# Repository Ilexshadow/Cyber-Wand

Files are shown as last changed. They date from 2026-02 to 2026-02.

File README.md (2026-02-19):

# 当麻瓜的电子技术遇见巫师的魔法世界 
- 此项目最初想制作一个可以用于游戏[霍格沃茨之遗](https://www.hogwartslegacy.com/en-us)的体感控制器。
- 现在能够做到
  - 通过该项目制作出的魔杖控制角色前后左右移动。
  - 通过挥舞该项目制作出的魔杖，产生特定的键盘输入，从而在游戏中释放特定的魔法。
  
&emsp;&emsp;具体情况可以见  详细介绍ppt  以及  真实游戏展示视频。    

- lyg09270的开源项目[Cyberry_Potter_Electromagic_Wand](https://github.com/lyg09270/Cyberry_Potter_Electromagic_Wand)对此项目有很大的启发作用，向其学习了部分代码和PCB设计，但是最终此项目所使用的Keil版本配置、PCB设计、数据处理与其都有所不同。  
- Keil除版本略新外，配置完全参照[江协科技STM32入门教程](https://www.bilibili.com/video/BV1th411z7sn)。  
- PCB设计使用[嘉立创EDA](https://pro.lceda.cn/)。EDA使用学习了b站up主[Expert电子实验室](https://www.bilibili.com/video/BV1At421h7Ui)的相关教程  
- 使用了majianjia的开源项目[nnom](https://github.com/majianjia/nnom)将Keras神经网络模型变为NNoM神经网络模型，从而可以置于MCU上。

&emsp;&emsp;非常感谢[lyg09270](https://github.com/lyg09270)、[majianjia](https://github.com/majianjia)、[江协科技](https://space.bilibili.com/383400717?spm_id_from=333.788.upinfo.detail.click)、[嘉立创EDA](https://pro.lceda.cn/)等提供的帮助。

- 主控芯片：STM32F103C8T6
- 姿态传感器：MPU6050。I2C通信、姿态解算。
- 无线通信：NRF24L01。SPI协议、无线数据传输。
- 电源管理：TP4056。充放电管理。
- PCB设计：嘉立创EDA。
- 软件开发：Keil MDK。

如果这个项目对你有帮助，欢迎点亮⭐

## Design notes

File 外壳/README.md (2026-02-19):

```外壳零件_T```是按钮，存在底座偏厚的情况。  
```外壳主体_B/T```是长方体外壳的上下盖，存在按钮开孔过小的情况。  
具体差距取决于3D打印的技术，需要打印后自己手工打磨。  
但是这个模型不够美观、也不够舒适，建议大家自己绘制，这里仅供参考。

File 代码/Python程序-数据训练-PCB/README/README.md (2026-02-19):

# 制作赛博魔杖的Cyber_Vlog之NNoM篇
[TOC]
## 配置NNoM所需环境
### 下载VSCode
### 配置Anaconda
- 配置完成后，在随便一个盘建一个新文件夹，在VSCode里面打开这个文件夹，之后我们将在这个文件夹里面进行操作。//*我这里是在E盘建了一个Cyber_Wand_Try文件夹*
- 同时新建一个虚拟环境,之后我们将在这个环境里面进行操作。//*我这里建的是try虚拟环境*
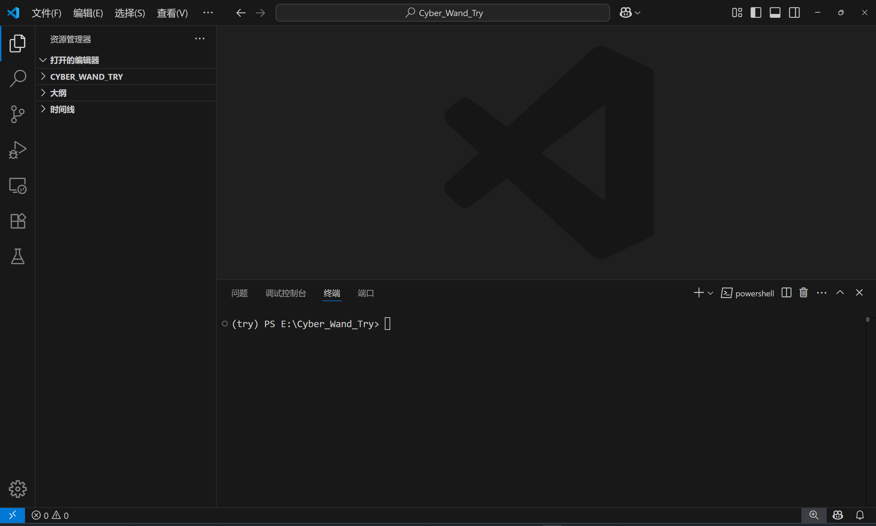
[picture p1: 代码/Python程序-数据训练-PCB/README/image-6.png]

- 安装一些必要的库。
  在终端运行命令行，等待一会就下载完成了
  ```
  pip install pandas
  pip install scons
  ``` 

### 配置NNom
我这里给出我自己的方式，不是万能也未必最佳  
#### 安装tensorflow和keras库
- 根据NNoM文档，需要tensorflow<=2.14.1,同时我们需要用到keras
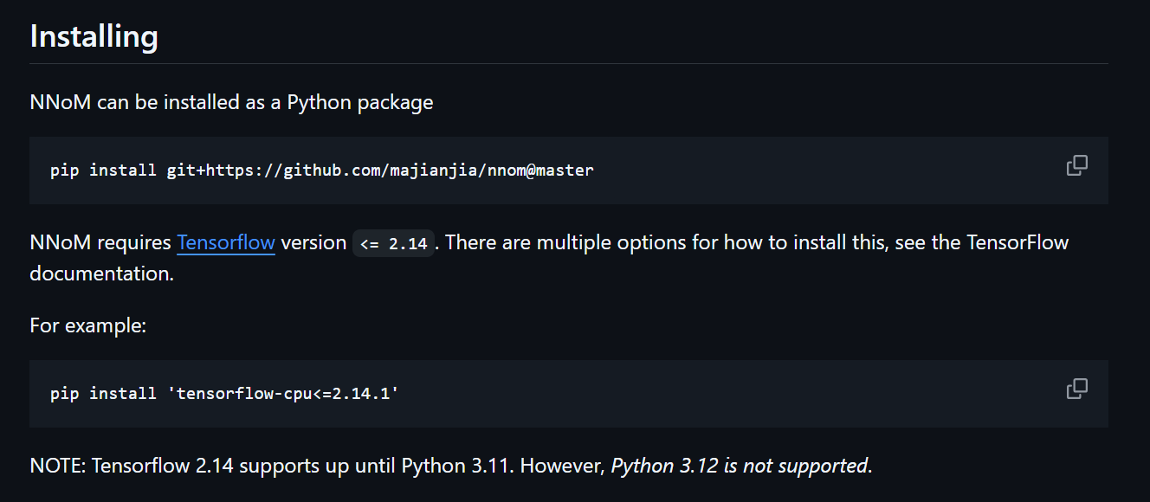
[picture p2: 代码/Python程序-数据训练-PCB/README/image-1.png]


- 而根据Keras官方网站，tensorflow和keras的版本兼容如下
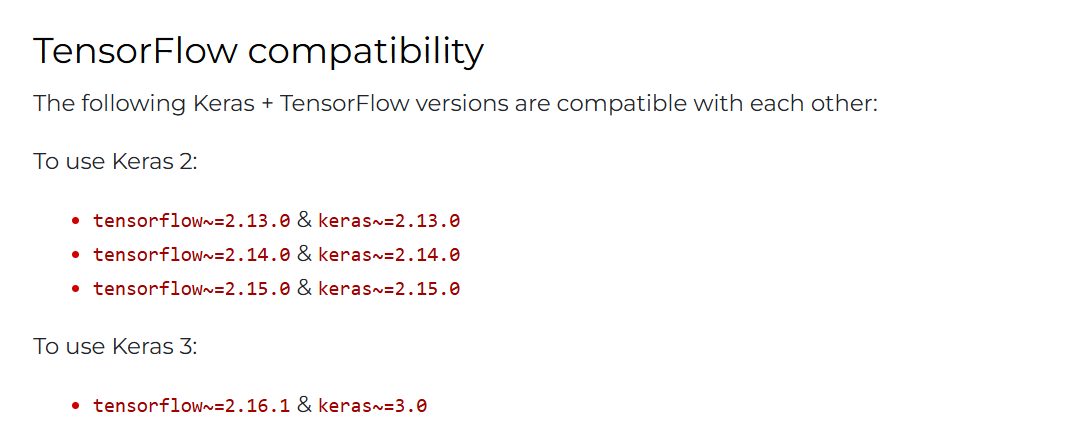
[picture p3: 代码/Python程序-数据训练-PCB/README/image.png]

- 官方文档还告诉我，安装tensorflow版本=2.14.0会自动安装上keras版本=2.14

- 所以我选择
  **tensorflow版本=2.14.0，keras版本=2.14.0**
- 在终端运行命令行，等待一会就下载完成了
    ```
    pip install tensorflow==2.14.0
    ```
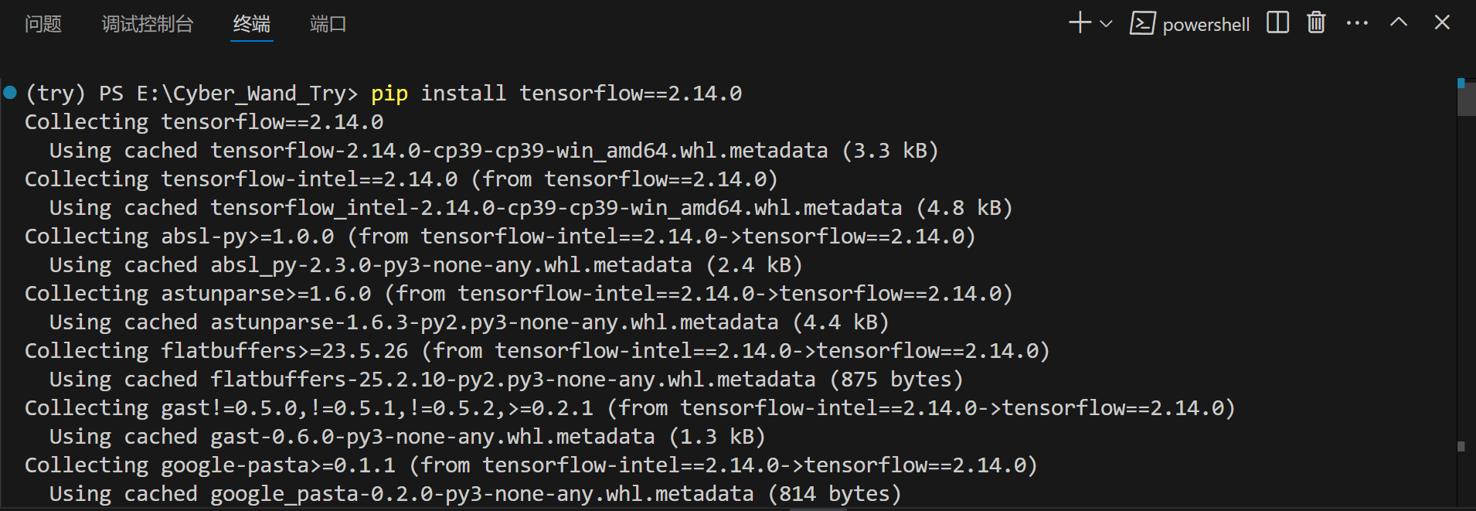
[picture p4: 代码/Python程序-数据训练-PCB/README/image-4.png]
   
- 这样就成功安装了tensorflow和keras库
  
#### 安装NNoM库
- 官方给出的办法是
  
- 但是由于我的梯子不是很稳定，经常下不下来，所以我选择另一种方法
- 打开Github上的NNoM项目，在绿色的"Code"处点击，选择"Download ZIP"，将整个项目打包下载下来。然后再解压缩。//*我这里是下载在E盘*
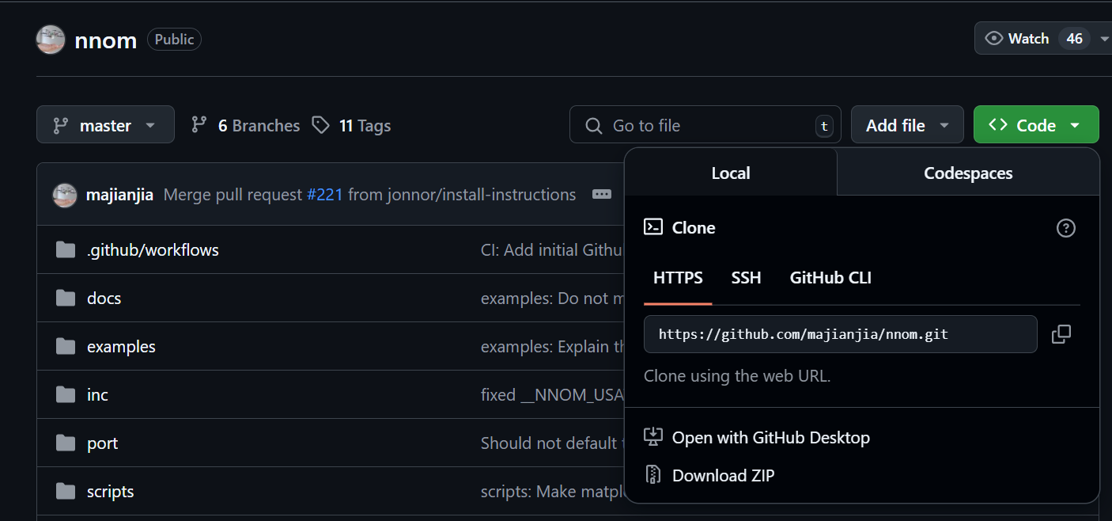
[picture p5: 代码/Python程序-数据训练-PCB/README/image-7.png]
  
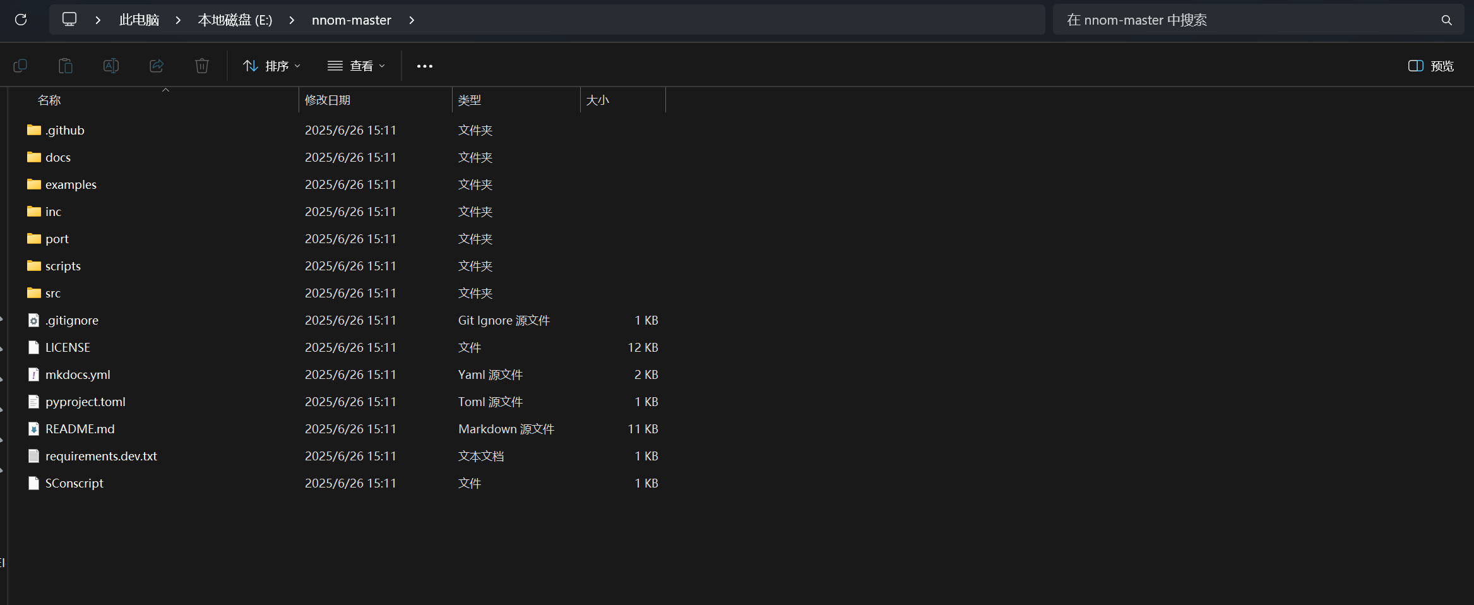
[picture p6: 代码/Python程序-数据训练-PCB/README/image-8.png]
  
- 在终端运行命令行，等待一会就下载完成了
  **注意我这里的"E:\nnom-master"是这个文件夹的路径，请根据你的实际情况修改**。可以找到你的解压后的文件夹，右键，选择“复制文件地址”，在命令行处粘贴来进行替换。
  ```
  pip install "E:\nnom-master"
  ```
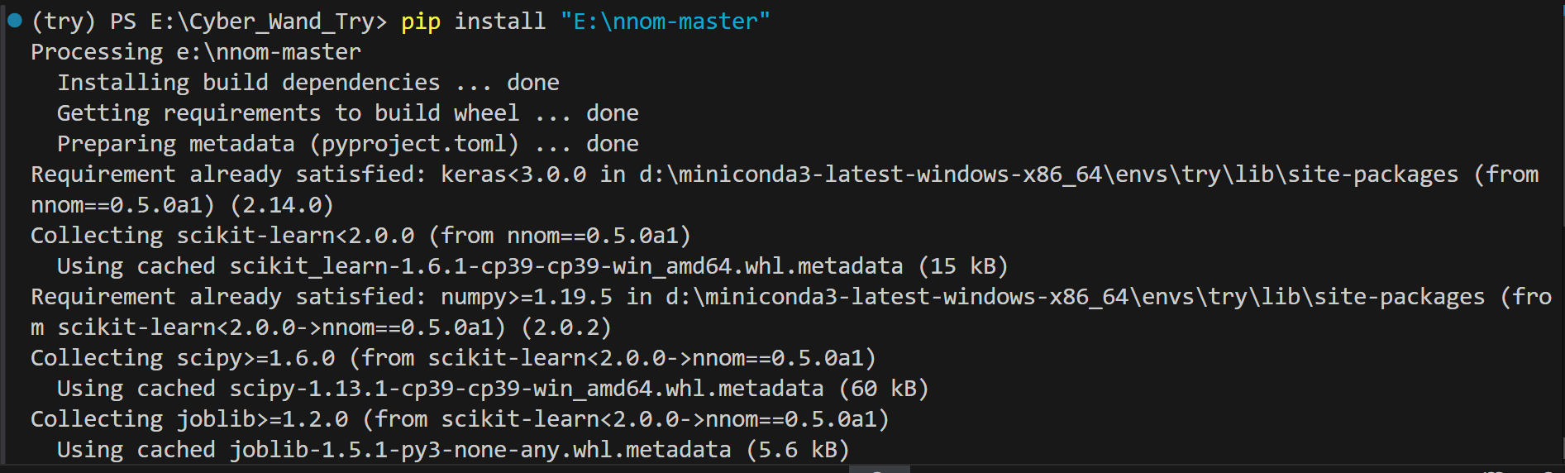
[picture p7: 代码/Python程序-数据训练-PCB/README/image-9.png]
  
- 可以看到最后这里就是成功的信息
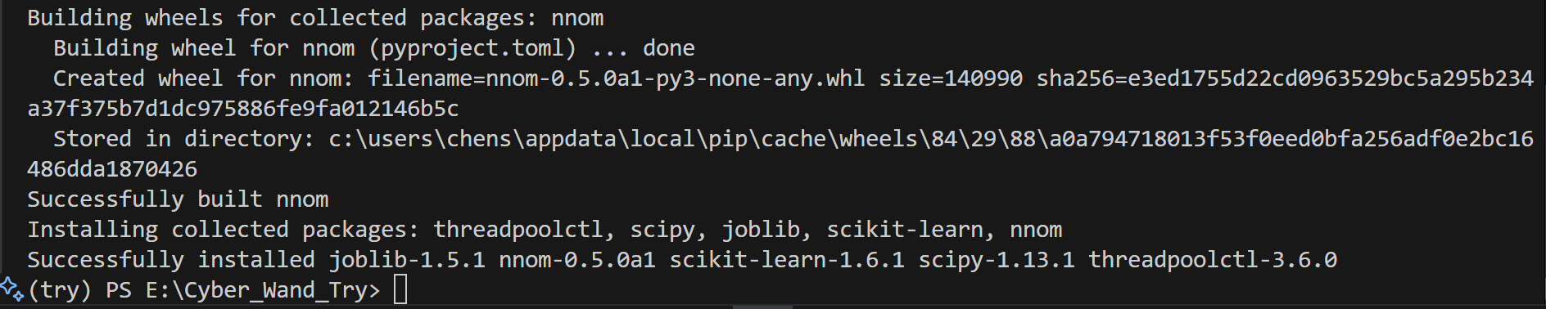
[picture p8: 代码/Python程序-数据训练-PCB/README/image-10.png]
  

## 训练模型并用NNoM转成可以在MCU上运行的格式
### 采集数据
- stm32通过USB-TTL连接电脑，通过运行collect_data.py采集数据 
- 采集的数据以csv格式储存在对应文件夹下，每个文件夹下是一个种类的动作
- 只需要修改7-9行配置参数的代码就行，尤其需要注意“串口号PORT”和“路径DATA_DIR”
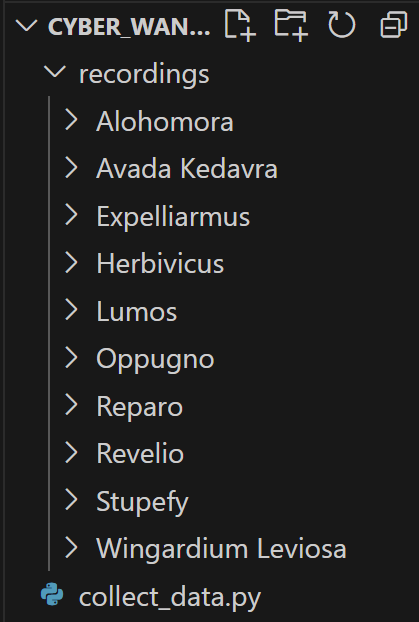
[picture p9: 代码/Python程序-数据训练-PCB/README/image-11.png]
  
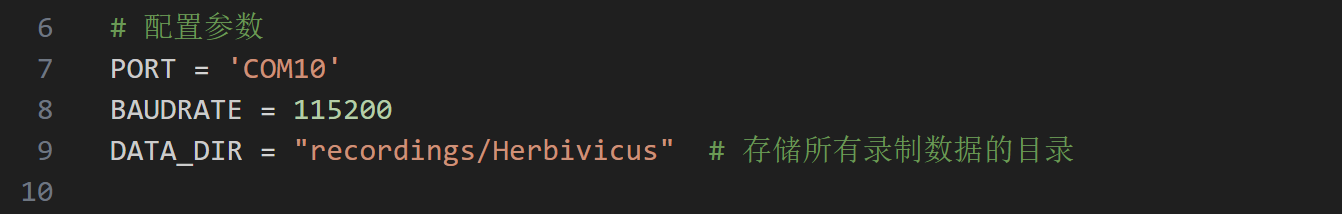
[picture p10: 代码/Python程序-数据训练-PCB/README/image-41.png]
  

### 搭建模型并用采集到的数据训练
本部分我采用了模块化的代码编写，尽量封装了一些函数，虽然过程上稍显繁琐，但个人认为思路清晰更为重要
#### 数据加载函数 
- load_data.py
- 可以去掉后面的注释，打印基本信息，以及让数据可视化，了解一下情况
- 如果你需要让数据可视化，不要忘了先在环境中安装matpotlib库
  在终端运行命令行，等待一会就下载完成了
  ```
  pip install matplotlib
  ```
- 我的打印出来是这样的，当然，由于大家recordings里面数据不同，有差别也很正常
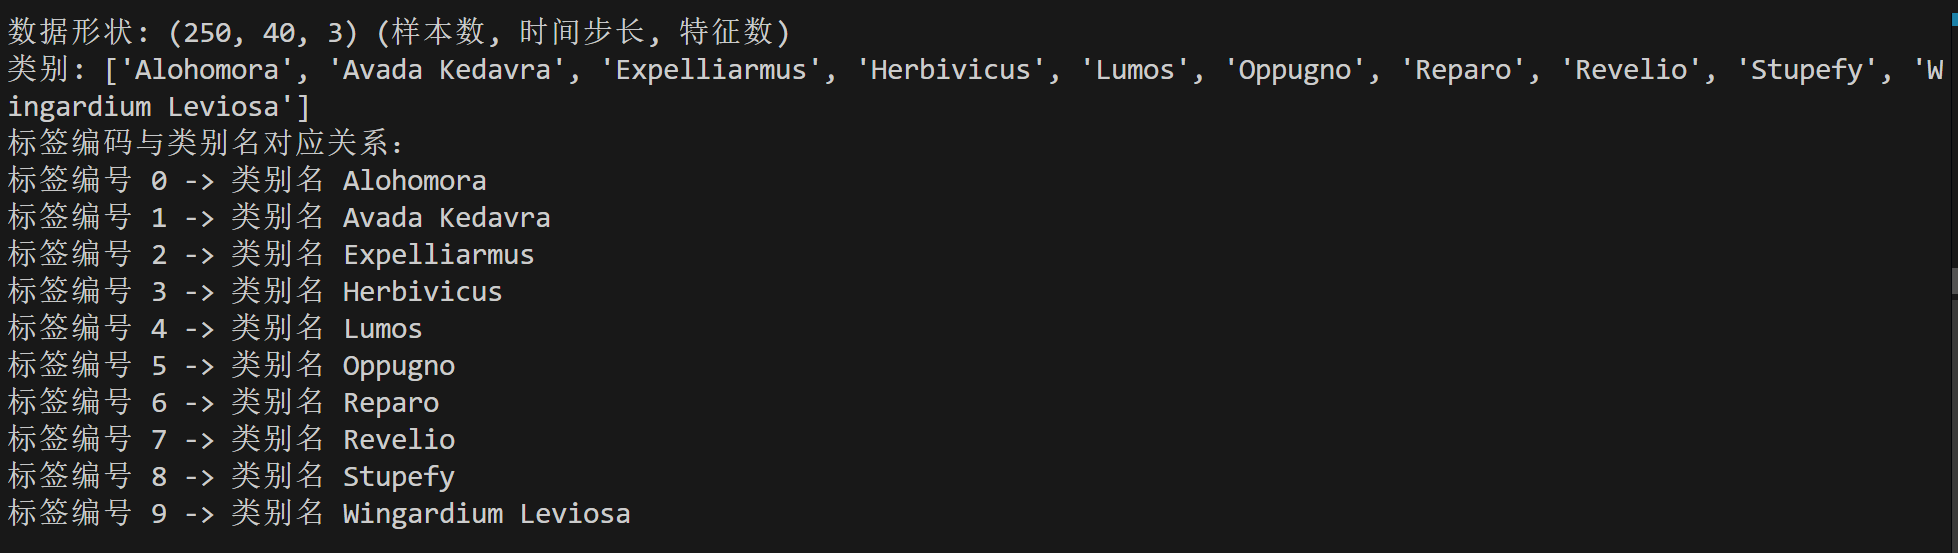
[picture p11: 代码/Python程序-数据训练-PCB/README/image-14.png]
  
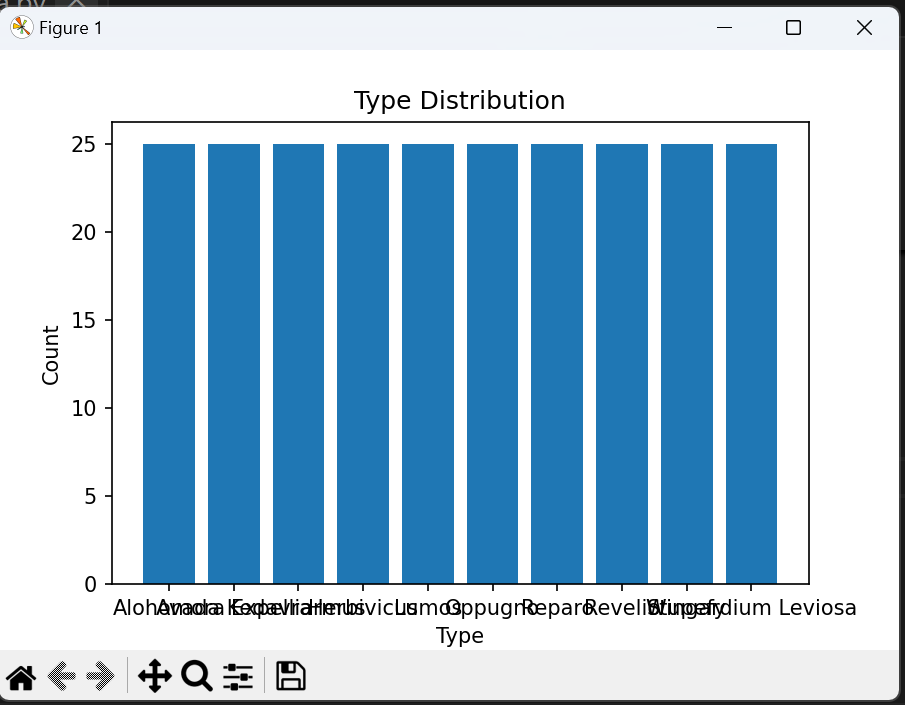
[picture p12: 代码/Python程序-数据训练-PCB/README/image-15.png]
  
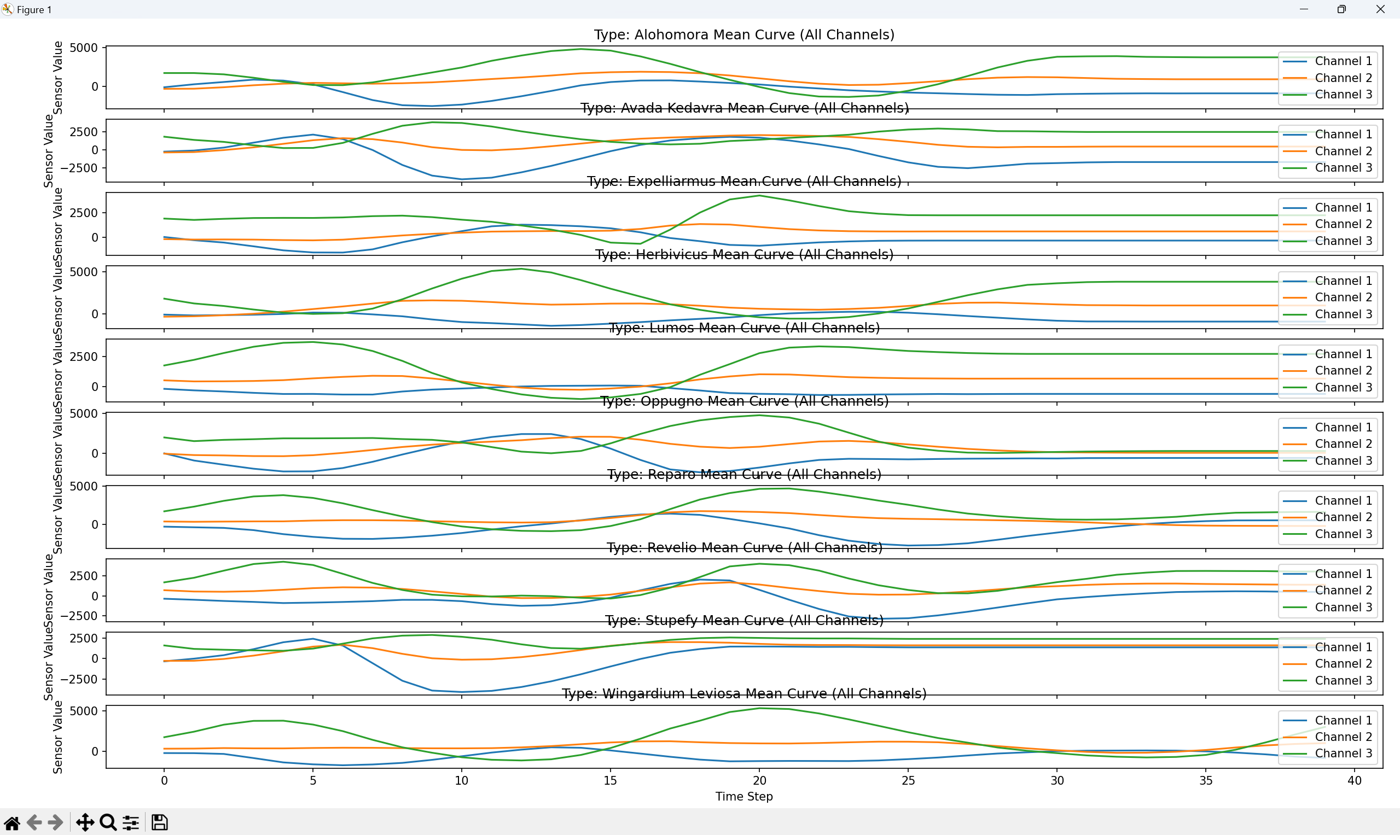
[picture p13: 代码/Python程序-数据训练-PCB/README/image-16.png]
  
#### 划分训练集和测试集
- split_data.py
#### 搭建模型函数
- build_model.py
- 这是一个错误例子
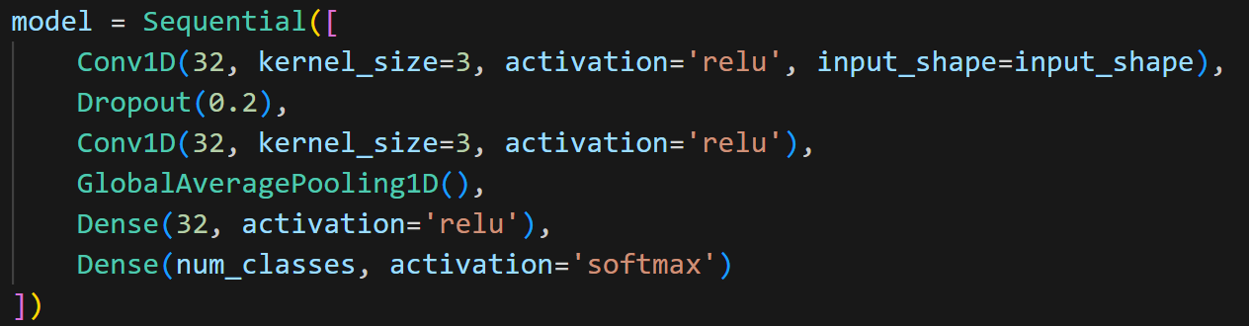
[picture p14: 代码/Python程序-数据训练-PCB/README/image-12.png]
  
  **1.不能写成sequential的形式  
  2.activation不能写在里面，要放在后面一行**
  这才是正确的
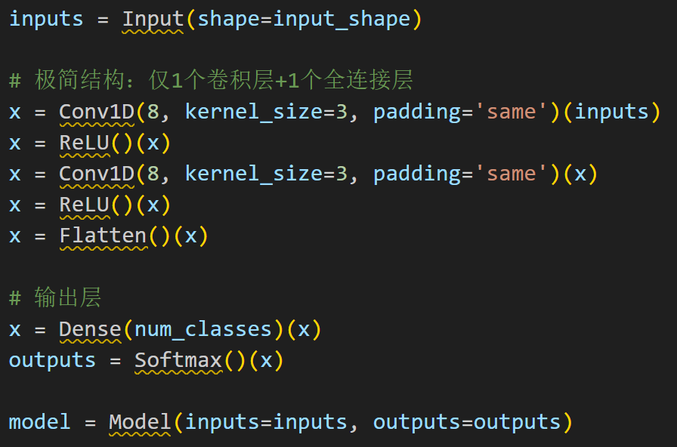
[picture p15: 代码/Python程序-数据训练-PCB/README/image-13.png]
  
- 模型的层数和每层的类型大家可以自己调整
#### 训练模型函数
- train_model.py
- 学习率、早停等大家可以自己调整
#### 在主函数调用以上函数并转换为NNoM模型
- main.py
- 这里需要在load_data和split_data之间加上
  ```
  X /= 32768.0
  y = to_categorical(y, num_classes=10)
  ```
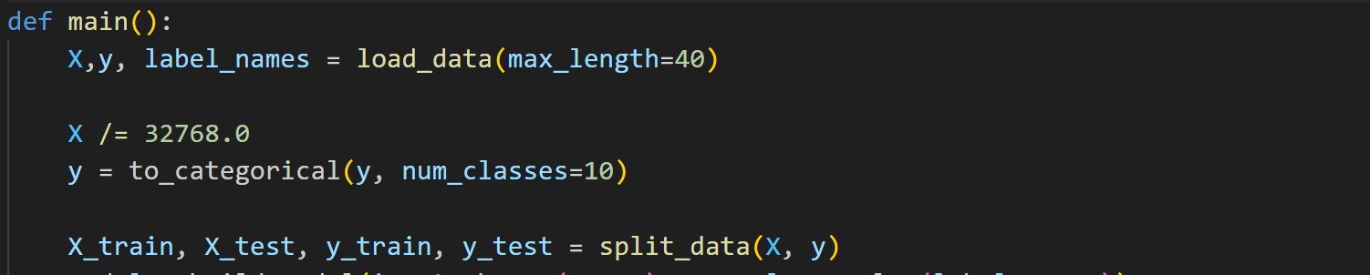
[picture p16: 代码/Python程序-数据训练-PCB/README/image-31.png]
  
  具体原因之后会讲到。
- NNoM这个库其实主要就用在generate这一步，得到的weights.h就是模型可以移植的样子。
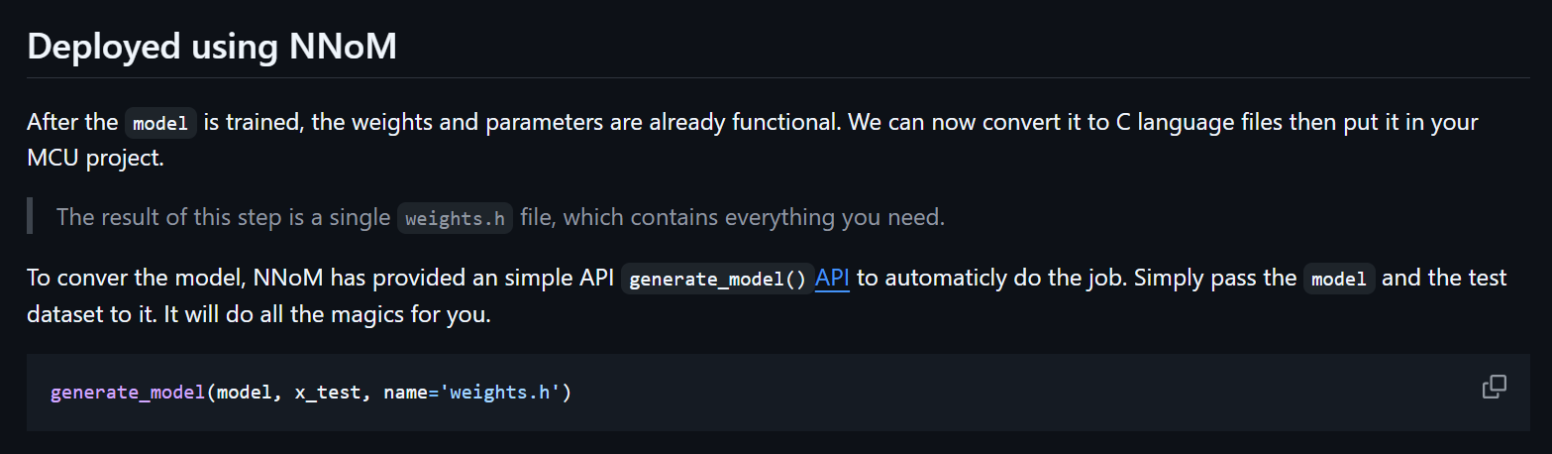
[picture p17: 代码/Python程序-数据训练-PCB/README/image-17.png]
  
- 你唯一可以改动的地方就是"weights.h"这个名字了。至于format能不能改，我也不是很确定。
- 生成weight.h的同时还会生成一个.layer_q_list文本文件，里面存了每一层量化的参数。这里的一些数据之后有用。其实这一部分的数据weights.h文件里面也有，就在那一堆绿色数字下面一点。
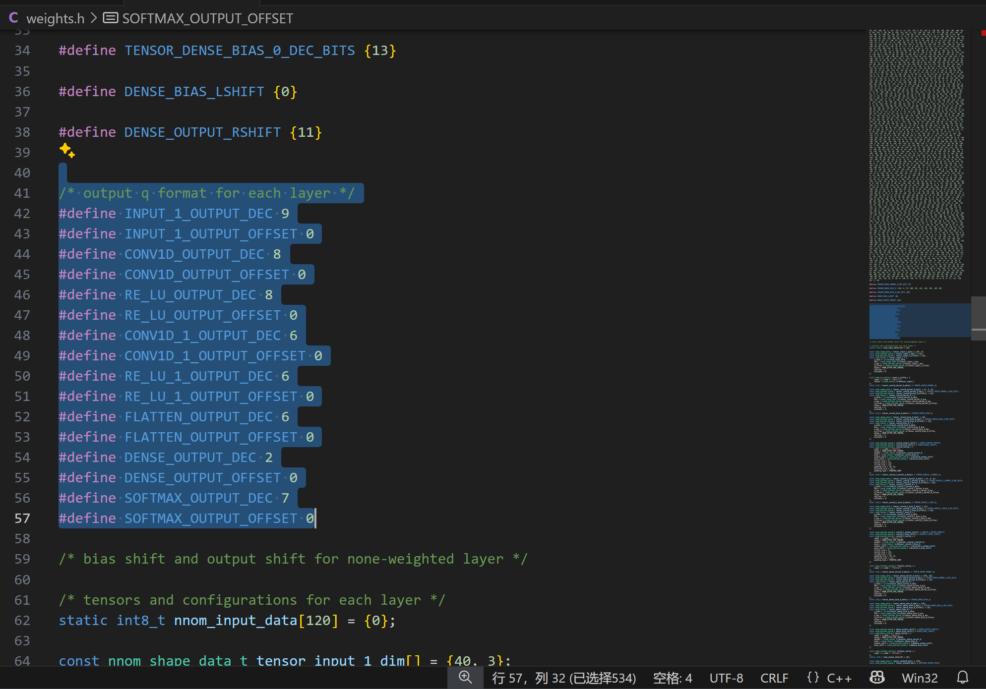
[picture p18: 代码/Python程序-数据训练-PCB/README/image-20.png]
  
- 如果你运行了 main.py,但是出现报错
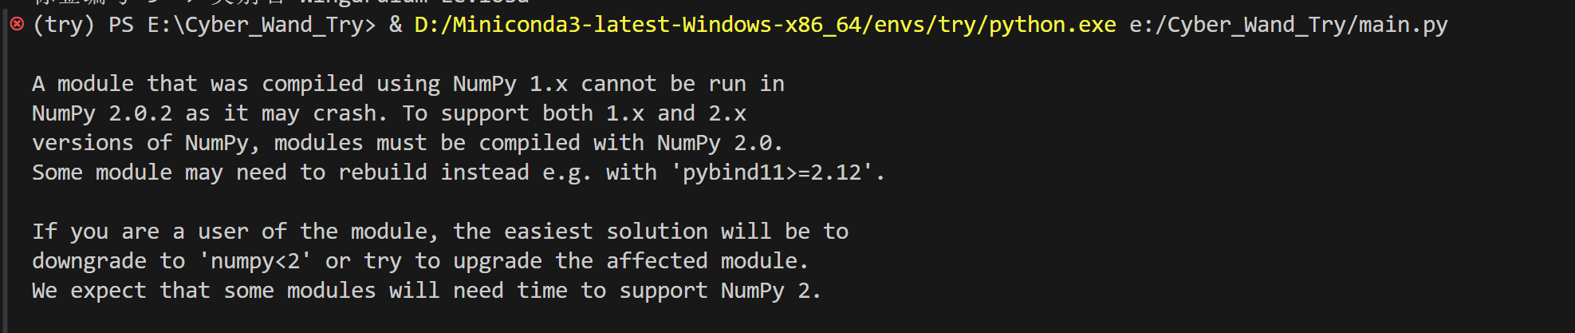
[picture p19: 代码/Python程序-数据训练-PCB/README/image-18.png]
  
  **看起来是因为我的numpy版本过高不兼容导致的，要求使用numpy版本=1.x**
  所以我重装了numpy库
  在终端运行命令行，等待一会就下载完成了
  ```
  pip install "numpy<2" --upgrade
  ```
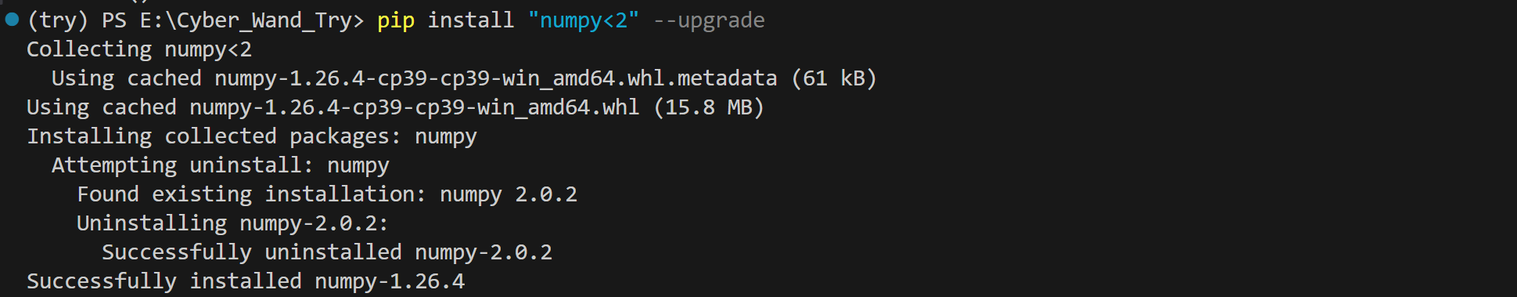
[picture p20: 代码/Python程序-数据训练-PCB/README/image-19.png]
  
  这样就可以正常运行了
- 如果出现其他报错，注意你的数据格式，形状、类型等等都会导致报错
### 用NNoM在电脑上进行评估
由于keras模型向nnom模型转换可能存在精度下降的问题，NNoM的开发者提供了一个在电脑上评估模型的程序，可以先在电脑上确认转换后的模型仍然有效再向MCU移植。
以下用到的文档其实在NNoM的仓库内基本都能找到，我们要做的只是做一些修改。
#### 修改得到auto_test.py及其他有用的文件
- 在你下载的文件夹中找到examples -> auto_test ->  main.py，复制到你现在的工作区并重命名为 auto_test.py
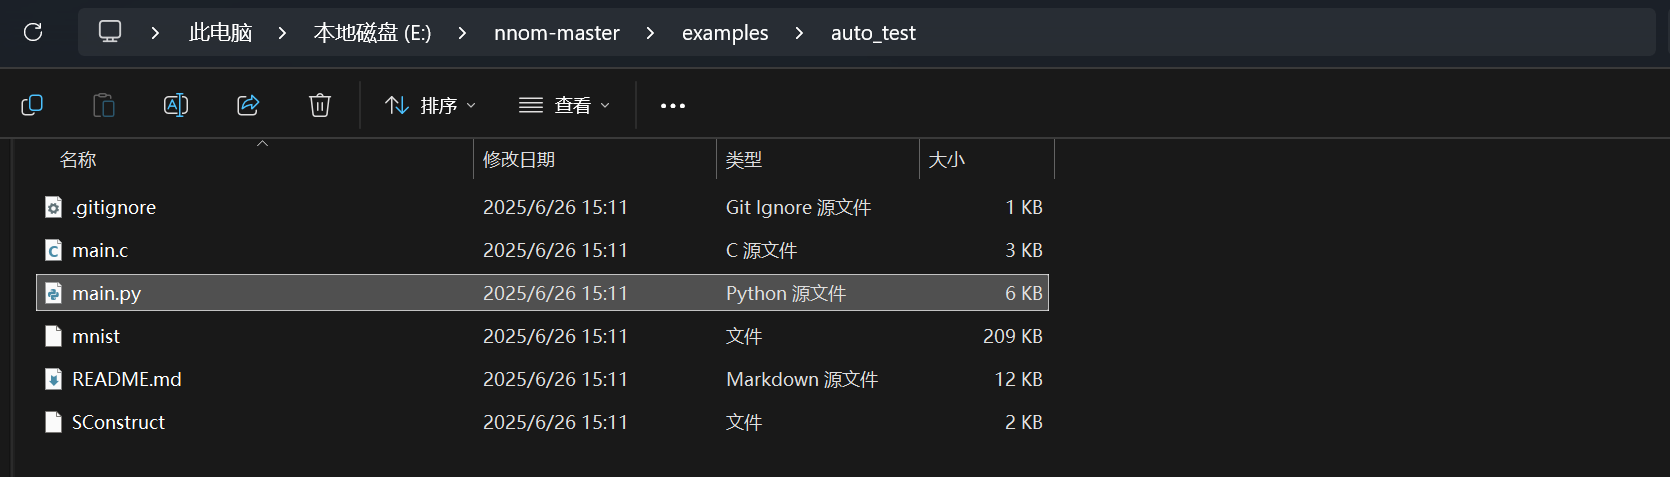
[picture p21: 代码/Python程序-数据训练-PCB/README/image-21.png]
  
  我们将在这个示例代码上做修改，得到我们真正需要的评估代码auto_test.py 
- 我们先来分析一下这个代码现在的意思
  - 开头是作者的一些信息
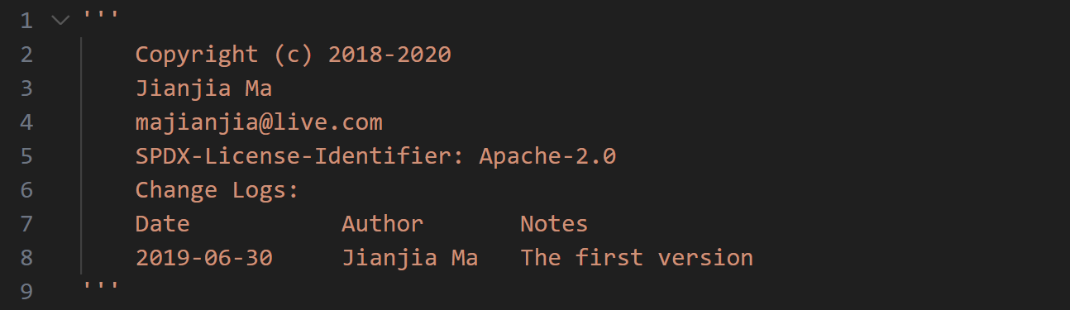
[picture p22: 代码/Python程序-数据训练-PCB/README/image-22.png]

  - 然后导入一些库
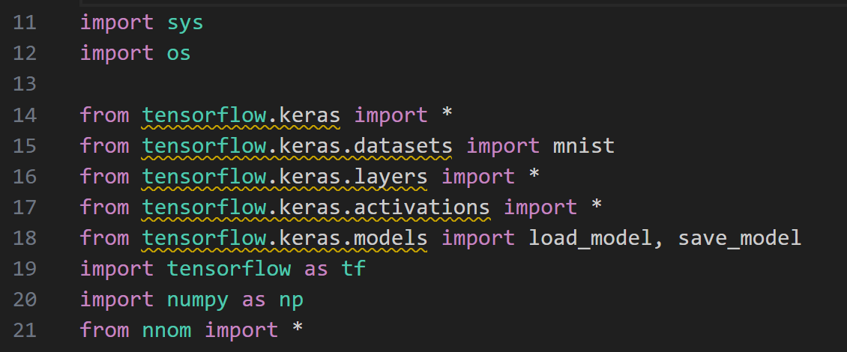
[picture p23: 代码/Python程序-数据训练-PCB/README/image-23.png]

  - build_model函数用于搭建模型
  - train_model函数用于训练模型，这里用到了前面定义的save_dir，也就是模型存在哪里
  - 主函数前面的部分我们之前都做过了
    - 加载数据
    - 划分数据
    - 搭建模型
    - 训练模型
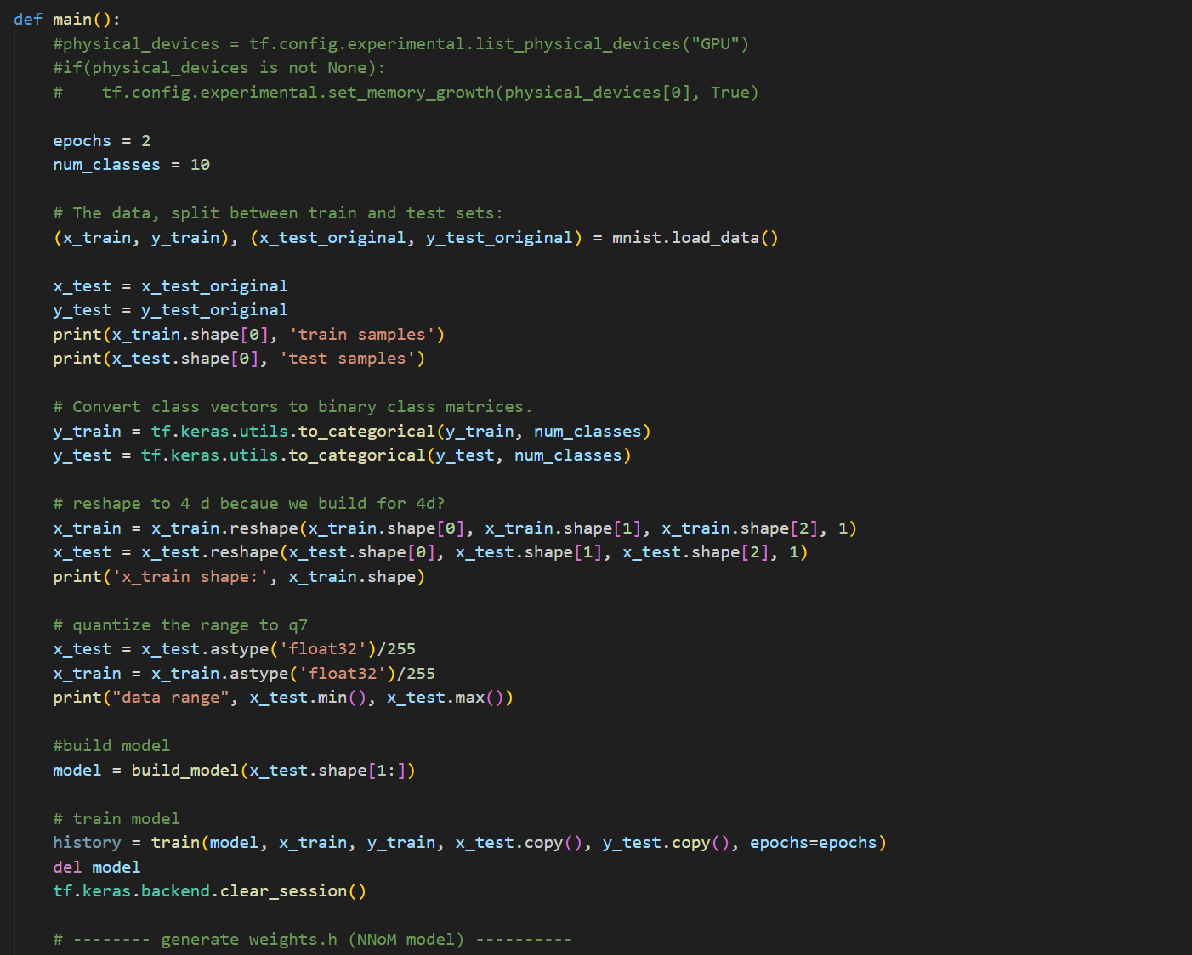
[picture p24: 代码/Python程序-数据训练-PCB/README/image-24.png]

  但要注意几个点：
  1. **这里对y形状的转换**
   这个好像示例代码有错，我在用的时候发现后面的y_train和y_test都应该加上_original的后缀才对
   
  2. **这里对X的量化**
  
  这就是为什么之前说需要在load_data和split_data之间加上
    ```
    X /= 32768.0
    y = to_categorical(y, num_classes=10)
    ```
  **这两个是一定要做的不然会报错**。但是X的量化是除以2的多少次方要根据你自己输入的数据来决定，我目前的理解是让它量化完接近1就行。
  - 主函数后面的部分基本是我们之前没有做过的事情
    - 先加载模型
    - 然后用一部分数据去生成test_data.bin，这个在之后的部分有用
    - 用score来反映keras模型好坏
    - 生成nnom模型weights.h
  
    - 简单来说，先是关于命令行简化的一些操作，为了方便后面使用，具体可以自己去查查，我也不是很懂
    - 然后自动运行一个exe文件
    - 算出一个acc用来评估nnom模型的准确度如何
  
- 理解了原来的代码在干什么，现在我们开始修改
1. 删掉作者信息
2. 我选择不把训练模型的部分放进去，而是直接载入训练好的模型，这样就不会每次运行都重新训练模型了,同时也不再重新生成weights.h。但是我们要把载入数据的部分放进去，因为生成test_data.bin需要用到。
   - 当然，你也可以把我们之前写好的load_data,split_data，trian_model,build_model直接换进去，把训练模型的部分从main.py全部移到auto_test.py里，这样就是在auto_test.py里面训练模型并生成weights.h，每次运行都重新训练模型并生成.h文件
3. 我们的数据没有这么多，所以把only use 1000 for test去掉
4. 关于简化命令行的操作，我不知道怎么用示例代码中的那种，所以我让ai帮忙写了个Makefile文件
   - Makefile的内容如下
     
   - 里面的具体内容跟你的项目结构有关系  //*我的文件结构如下图，nnom文件夹下的3个文件夹都是从Github上下载的那个文件夹里面复制过来的，Makefile直接放在Cyber_Wand_Try文件夹里面*
    
    
   - 在终端运行命令行
      ```
      mingw32-make all
      ```
      就可以得到auto_test.exe以及auto_test.o 
   - 而auto_test.c的来源跟auto_test.py一样，是把main.c复制过来重命名即可
5. 由于我们把名字改成了auto_test.exe，所以cmd那句也跟着改

如果是linux用户要自己再修改一下
1. 需要的东西就都用了，接下来运行auto_test.py即可  
   
  这里就是keras模型和nnom模型各自的准确率啦，如果你比较满意的话，就可以把它移植到MCU上了

## 把NNoM模型移植到MCU上
### 添加需要的文件
#### 把需要的文件放到文件夹中
1. 在项目文件夹里面新建一个nnom文件夹
2. 把需要的文件复制进来
   
   **我们只需要Github上下载文件夹里面inc，port，src这三个文件夹，以及之前生成的weights.h模型文件**
#### 把需要的文件从文件夹添加到项目
1. 在Keil 5 MDK打开原来项目，在Target下add group，命名为nnom
2. 把上一步那个nnom文件夹里的所有文件都add进来
3. 添加它们的路径，**有文件的每一级都要添加**
   
### 在主函数中调用
#### 修改nnom_port.h文件
把第20行解除注释，这样可以使用静态内存

#### 修改main.c
根据官方文档
 
我们目前知道的以及该做的事情有
- 需要添加头文件
  ```
  #include <math.h>   //量化要用到阶乘pow函数，这个之后会知道
  #include "nnom.h"
  #include "weights.h"
  ```
- 定义model变量
  ```
  nnom_model_t *model;
  ```
- 给model赋值
  ```
  model = nnom_model_create();
  ```
- 在需要使用model的时候调用
  ```
  model_run(model);
  ```

那么除此之外还有那些事情要做呢？
官方文档还告诉我们：

现在我们知道模型的输入和输出是存在哪里的了，那就对原有的输入和输出部分做相应的修改吧
- 把读到的数据存到nnom_input_buffer[]里
1.  我们先定义一个数组来存MPU6050的数据
  ```
  float mpu6050_acc[40][3] = {0} ;    
  ```
2. 在主函数中，按下按钮开始录制时，本来要向串口输出的MPU6050数据现在要存在这里。那么我们就在有串口输出数据的部分都加上
  ```
  mpu6050_acc[motion_index][0] = AccX / 32768.0;  //32768.0就是前面让它接近1的那个量化值
  mpu6050_acc[motion_index][1] = AccY / 32768.0;
  mpu6050_acc[motion_index][2] = AccZ / 32768.0;
  ```
  其中motion_index表示现在是一个样本的第几组数据了,记得在前面定义
  ```
  uint8_t motion_index
  ```
3. 定义一个函数nnom_feed_input()
  ```
  void nnom_feed_input(void)
  {
    uint8_t i = 0;
    double scale = pow(2,INPUT_1_OUTPUT_DEC);   //这个是跟量化有关的，INPUT_1_OUTPUT_DEC在.layer_q_list里面可以找到，weights.h里面也有
    for(i = 0;i < 40; i++)
    {
      nnom_input_data[i*3] = (int8_t)round(mpu6050_acc[i][0]*scale);
      nnom_input_data[i*3+1] = (int8_t)round(mpu6050_acc[i][1]*scale);
      nnom_input_data[i*3+2] = (int8_t)round(mpu6050_acc[i][2]*scale);
    }
  }
  ```
调用这个函数就能把数据存到nnom_input_data[]里了
这里的40跟训练模型用的样本长度有关
- 从nnom_output_buffer[]读出结果并从串口输出
  定义一个函数nnom_get_output
  ```
  void nnom_get_output(void)
  {
    model_run(model);
    uint8_t i = 0;
    for(i = 0;i < 10;i++)
    {
      float output = (float)nnom_output_data[i] /127 *100;    //除以127跟auto_test.py里面的*127有关系
      printf("output[%d]=%.2f%%\n",i,output);   //以百分数格式输出
    } 
  }
  ```
  调用这个函数就能把结果输出在串口了
  这里的10跟总共要区分的种类有关

- 此外我们还要做一些定义，至于为什么要做这些定义我并没有找到说明。我个人的理解是开辟一个静态内存缓冲区，大小为8KB，这样既能满足轻量级神经网络的需求，又能保证确定性较高的内存使用(8*1024字节)
  ```
  #ifdef NNOM_USING_STATIC_MEMORY   //写在最前面
  static uint8_t nnom_buffer[8*1024];
  #endif

  #ifdef NNOM_USING_STATIC_MEMORY   //写在主函数里
  nnom_set_static_buf(nnom_buffer, sizeof(nnom_buffer));
  #endif
  ```
  通过实践可以知道的是，**一定要把它们放在#ifdef和#endif之间**，不然就会出现问题
- 注意每次预测结束后，一些变量要清零
## 到此为止圆满结束！撒花！
2025.06.28 1：38，北京 清华大学 紫荆学生公寓4号楼

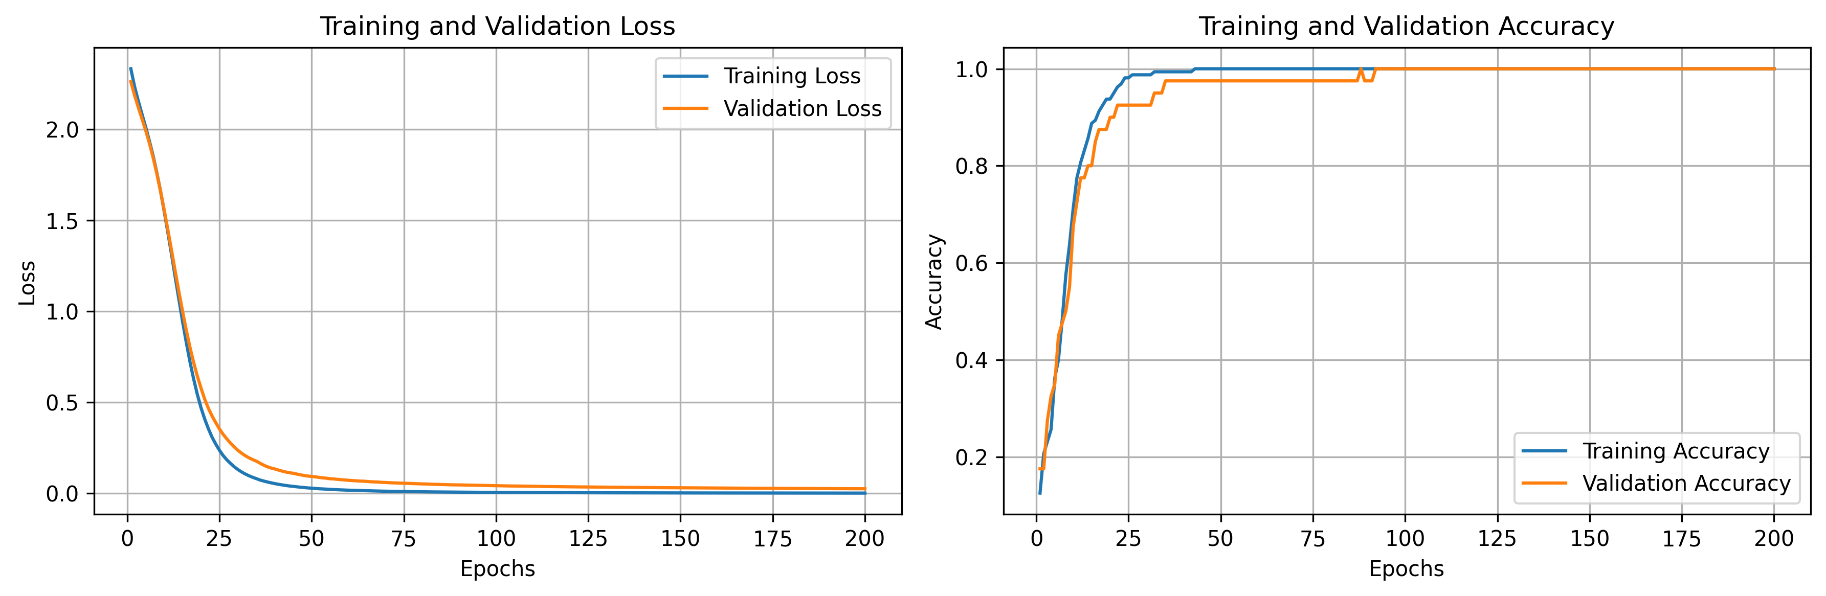
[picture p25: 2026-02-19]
代码/Python程序-数据训练-PCB/training_curves.png

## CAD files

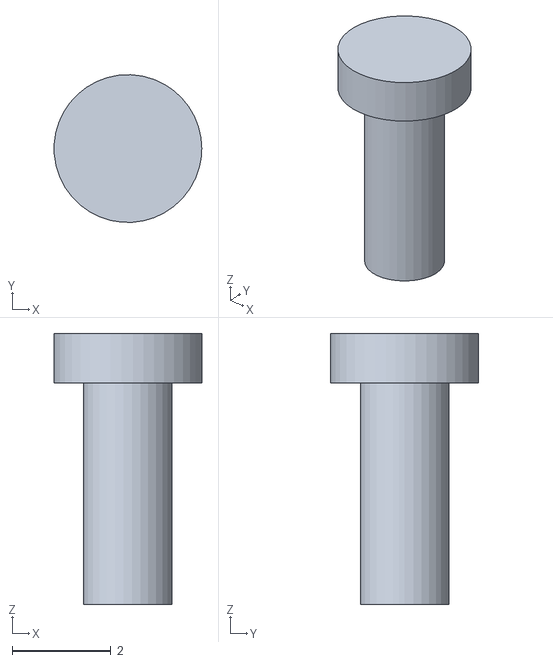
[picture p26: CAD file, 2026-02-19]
外壳/3DShell_外壳零件_T.stl
3.00 x 3.00 x 5.50

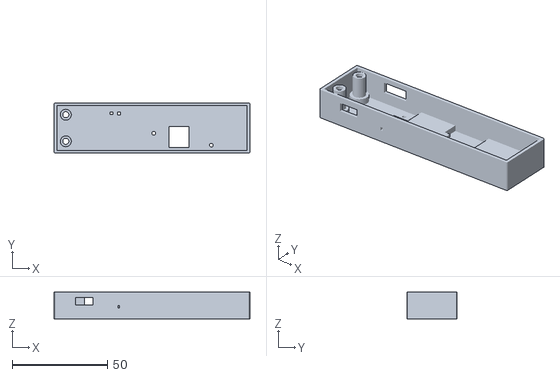
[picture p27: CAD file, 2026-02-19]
外壳/3DShell-外壳主体_B.stl
103.0 x 26.4 x 14.0

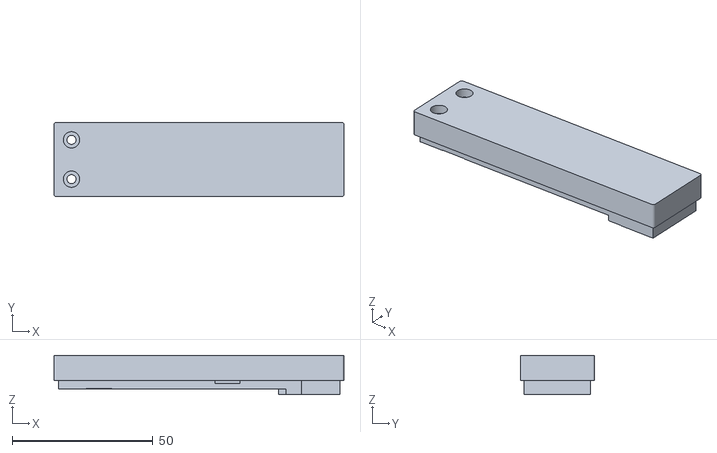
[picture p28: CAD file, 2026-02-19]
外壳/3DShell-外壳主体_T.stl
103.0 x 26.4 x 14.0

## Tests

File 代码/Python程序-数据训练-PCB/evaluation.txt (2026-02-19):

Runing time: 0us
Test loss:0.001078156172297895
Top 1:1.0
4,0,0,0,0,0,0,0,0,0
0,4,0,0,0,0,0,0,0,0
0,0,4,0,0,0,0,0,0,0
0,0,0,4,0,0,0,0,0,0
0,0,0,0,4,0,0,0,0,0
0,0,0,0,0,4,0,0,0,0
0,0,0,0,0,0,4,0,0,0
0,0,0,0,0,0,0,4,0,0
0,0,0,0,0,0,0,0,4,0
0,0,0,0,0,0,0,0,0,4

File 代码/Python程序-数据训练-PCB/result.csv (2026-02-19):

label | prob
1 | 1.000000
2 | 1.000000
5 | 1.000000
6 | 1.000000
1 | 1.000000
9 | 1.000000
3 | 1.000000
8 | 1.000000
7 | 1.000000
4 | 1.000000
6 | 1.000000
8 | 1.000000
3 | 1.000000
4 | 1.000000
0 | 1.000000
7 | 1.000000
9 | 1.000000
3 | 1.000000
4 | 1.000000
9 | 1.000000
9 | 1.000000
1 | 1.000000
3 | 1.000000
8 | 1.000000
2 | 1.000000
2 | 1.000000
0 | 1.000000
1 | 1.000000
4 | 1.000000
6 | 1.000000
8 | 1.000000
2 | 1.000000
6 | 1.000000
0 | 1.000000
5 | 1.000000
5 | 1.000000
7 | 1.000000
5 | 1.000000
0 | 1.000000
7 | 1.000000

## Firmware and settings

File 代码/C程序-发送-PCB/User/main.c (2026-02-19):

//==========头文件============
#include "stm32f10x.h"
#include "gpio.h"
#include "spi.h"
#include "usart.h"
#include "delay.h"
#include "MyDelay.h"
#include "24L01.h"
#include "stdio.h"
#include "MPU6050.h"

#include "string.h"
#include "math.h"

#include "nnom.h"
#include "weights.h"

//========常见字符扫描码========
#define KEY_A 0x04
#define KEY_B 0x05
#define KEY_C 0x06
#define KEY_D 0x07
#define KEY_E 0x08
#define KEY_F 0x09
#define KEY_G 0x0A
#define KEY_H 0x0B
#define KEY_I 0x0C
#define KEY_J 0x0D
#define KEY_K 0x0E
#define KEY_L 0x0F
#define KEY_M 0x10
#define KEY_N 0x11
#define KEY_O 0x12
#define KEY_P 0x13
#define KEY_Q 0x14
#define KEY_R 0x15
#define KEY_S 0x16
#define KEY_T 0x17
#define KEY_U 0x18
#define KEY_V 0x19
#define KEY_W 0x1A
#define KEY_X 0x1B
#define KEY_Y 0x1C
#define KEY_Z 0x1D
#define KEY_SPACE 0x2C
#define KEY_ENTER 0x28
#define KEY_1 0x1E
#define KEY_2 0x1F
#define KEY_3 0x20
#define KEY_4 0x21
#define KEY_5 0x22
#define KEY_6 0x23
#define KEY_7 0x24
#define KEY_8 0x25
#define KEY_9 0x26
#define KEY_0 0x27

//========NRF24L01+模块连线========
/*
CSN		PB12
CE		PA8
MOSI	PB15
SCK		PB13
IRQ		没有用到
MISO	PB14
*/

//------------------------------------------------------------------------------
uint8_t key_new[6]; // 扫描5个按键的数组  每个数存储一个按键的值   按下是1   不按是0
uint8_t key_old[6]; // 用于存储上一次的按键值

uint8_t isRecording = 0; // 是否在录制

uint8_t result = 100; // 动作识别的结果

#ifdef NNOM_USING_STATIC_MEMORY	//使用静态内存
static int8_t nnom_buffer[8 * 1024];
#endif


nnom_model_t *model;

#define QUANTIFICATION_SCALE (pow(2, INPUT_1_OUTPUT_DEC))
#define CALIBRATION_SAMPLES 5 // 使用前5行进行校准
#define ALPHA 0.3f // 低通滤波系数 (0-1之间，越小滤波越强)
#define maxlength 100

int16_t AX, AY, AZ, GX, GY, GZ; // 定义用于存放各个数据的变量
uint8_t motion_index = 0;
float mpu6050_acc[maxlength][3] = {0};
float calibration_mean[3] = {0}; // 存储前三列的平均值
float filtered_acc[maxlength][3] = {0};     // 存储滤波后的数据

void low_pass_filter(float *input, float *output, float alpha, int is_first_run) 
{
    if (is_first_run) {
        *output = *input;  // 第一次运行时直接赋值
    } else {
        *output = alpha * (*input) + (1 - alpha) * (*output);
    }
}

void apply_low_pass_filter()// 批量低通滤波处理
{
    for (int i = 0; i < maxlength; i++) {
        for (int j = 0; j < 3; j++) {
            low_pass_filter(&mpu6050_acc[i][j], &filtered_acc[i][j], ALPHA, (i == 0));
        }
    }
}

void nnom_feed_input() // 模型数据输入
{
    uint8_t i = 0;
    double scale = QUANTIFICATION_SCALE;
			
    // 应用低通滤波（每列独立滤波）
    for (int col = 0; col < 3; col++) {
        for (i = 0; i < maxlength; i++) {
            if (i == 0) {
                filtered_acc[i][col] = mpu6050_acc[i][col]; // 第一个数据直接使用
            } else {
                filtered_acc[i][col] = ALPHA * mpu6050_acc[i][col] + (1 - ALPHA) * filtered_acc[i-1][col];
            }
        }
    }

    // 计算校准平均值（使用前CALIBRATION_SAMPLES行滤波后的数据）
   for (int col = 0; col < 3; col++)
        {
            calibration_mean[col] = 0;
            for (i = 0; i < CALIBRATION_SAMPLES; i++)
            {
                calibration_mean[col] += filtered_acc[i][col];
            }
            calibration_mean[col] /= CALIBRATION_SAMPLES;
        }

    // 处理数据并量化
    for (i = 0; i < maxlength; i++)
    {
        float processed_value;

        float acc0 = filtered_acc[i][0];
        float acc1 = filtered_acc[i][1];
        float acc2 = filtered_acc[i][2];
 
        // 第1列：减去平均值后除以1000
        processed_value = (acc0 - calibration_mean[0]) / 1000.0f;
        nnom_input_data[i * 3] = (int8_t)round(processed_value * scale);

        // 第2列：减去平均值后除以1000
        processed_value = (acc1 - calibration_mean[1]) / 1000.0f;
        nnom_input_data[i * 3 + 1] = (int8_t)round(processed_value * scale);

        // 第3列：减去平均值后除以2000
        processed_value = (acc2 - calibration_mean[2]) / 2000.0f;
        nnom_input_data[i * 3 + 2] = (int8_t)round(processed_value * scale);
    }
}

void nnom_get_output() // 模型结果输出
{
    model_run(model);

    float max_output = -1;
    uint8_t max_i = 100;

    uint8_t i = 0;
    for (i = 0; i < 10; i++)
    {
        float output = (float)nnom_output_data[i] / 127 * 100;
				printf("output[%d] = %f %%\n",i,output);
        if (output > max_output)
        {
            max_output = output;
            max_i = i;
        }
    }
    result = max_i;
}

void send_result(uint8_t result) // 根据识别到的结果发送对应按键
{
    if (result == 1)
    {
        Send_2401(KEY_1);           // 无线发送数据   代表1键按下了
        printf("1_Lumos\n");
        delay_ms(100);

        Send_2401(0x00); // 无线发送数据   0x00是按键清零
        delay_ms(100);
        Send_2401(0x00); // 无线发送数据   0x00是按键清零   再次发送，防止收不到数据
    }
    else if (result == 2)
    {
        Send_2401(KEY_2);           // 无线发送数据   代表2键按下了
        printf("2_Stupefy\n");
        delay_ms(100);

        Send_2401(0x00); // 无线发送数据   0x00是按键清零
        delay_ms(100);
        Send_2401(0x00); // 无线发送数据   0x00是按键清零   再次发送，防止收不到数据
    }
    else if (result == 3)
    {
        Send_2401(KEY_3);           // 无线发送数据   代表3键按下了
        printf("3_Alohomora\n");
        delay_ms(100);

        Send_2401(0x00); // 无线发送数据   0x00是按键清零
        delay_ms(100);
        Send_2401(0x00); // 无线发送数据   0x00是按键清零   再次发送，防止收不到数据
    }
    else if (result == 4)
    {
        Send_2401(KEY_4);           // 无线发送数据   代表4键按下了
        printf("4_Oppugno\n");
        delay_ms(100);

        Send_2401(0x00); // 无线发送数据   0x00是按键清零
        delay_ms(100);
        Send_2401(0x00); // 无线发送数据   0x00是按键清零   再次发送，防止收不到数据
    }
    else if (result == 5)
    {
        Send_2401(KEY_5);           // 无线发送数据   代表5键按下了
        printf("5_Avada Kedavra\n");
        delay_ms(100);

        Send_2401(0x00); // 无线发送数据   0x00是按键清零
        delay_ms(100);
        Send_2401(0x00); // 无线发送数据   0x00是按键清零   再次发送，防止收不到数据
    }
    else if (result == 6)
    {
        Send_2401(KEY_6);           // 无线发送数据   代表6键按下了
        printf("6_Metelojinx Recanto\n");
        delay_ms(100);

        Send_2401(0x00); // 无线发送数据   0x00是按键清零
        delay_ms(100);
        Send_2401(0x00); // 无线发送数据   0x00是按键清零   再次发送，防止收不到数据
    }
    else if (result == 7)
    {
        Send_2401(KEY_7);           // 无线发送数据   代表7键按下了
        printf("7_Reparo\n");
        delay_ms(100);

        Send_2401(0x00); // 无线发送数据   0x00是按键清零
        delay_ms(100);
        Send_2401(0x00); // 无线发送数据   0x00是按键清零   再次发送，防止收不到数据
    }
    else if (result == 8)
    {
        Send_2401(KEY_8);           // 无线发送数据   代表8键按下了
        printf("8_Expelliarmus\n");
        delay_ms(100);

        Send_2401(0x00); // 无线发送数据   0x00是按键清零
        delay_ms(100);
        Send_2401(0x00); // 无线发送数据   0x00是按键清零   再次发送，防止收不到数据
    }
    else if (result == 9)
    {
        Send_2401(KEY_9);           // 无线发送数据   代表9键按下了
        printf("9_Expecto Patronum\n");
        delay_ms(100);

        Send_2401(0x00); // 无线发送数据   0x00是按键清零
        delay_ms(100);
        Send_2401(0x00); // 无线发送数据   0x00是按键清零   再次发送，防止收不到数据
    }
    else if (result == 0)
    {
        Send_2401(KEY_0);           // 无线发送数据   代表0键按下了
        printf("10_Incendio\n");
        delay_ms(100);

        Send_2401(0x00); // 无线发送数据   0x00是按键清零
        delay_ms(100);
        Send_2401(0x00); // 无线发送数据   0x00是按键清零   再次发送，防止收不到数据
    }
}

// 扫描按键，并处理，如果有按键按下了，新的按键值是0，上一次的按键值是1，就说明有按键按下的动作
void read_key(void)
{
    key_new[0] = READ_B0;  // 读端口PB0电平，不按是1   按下是0 ==W
    key_new[1] = READ_A7;  // 读端口PB10电平，不按是1   按下是0 ==A
    key_new[2] = READ_B10; // 读端口PA7电平，不按是1   按下是0 ==S
    key_new[3] = READ_B11; // 读端口PB11电平，不按是1   按下是0 ==D
    key_new[4] = READ_B1;  // 读端口PB10电平，不按是1   按下是0 ==Space
    key_new[5] = READ_A6;  // 读端口PA6电平，不按是1   按下是0 ==Recoed

    // W
    if ((key_new[0] == 0) && (key_old[0] == 1)) // key1 按下   发W按下
    {
        Send_2401(KEY_W);           // 无线发送数据   0x1A是按键值   代表W键按下了
        delay_ms(100);
    }
    if ((key_new[0] == 1) && (key_old[0] == 0)) // key1 抬起   发8个字节0
    {
        Send_2401(0x00); // 无线发送数据   0x00是按键清零
        delay_ms(100);
        Send_2401(0x00); // 无线发送数据   0x00是按键清零   再次发送，防止收不到数据
    }

    // A
    if ((key_new[1] == 0) && (key_old[1] == 1)) // key2 按下   发A按下
    {
        Send_2401(KEY_A);           // 无线发送数据   0x04是按键值  代表A键按下了
        delay_ms(100);
    }
    if ((key_new[1] == 1) && (key_old[1] == 0)) // key2 抬起   发8个字节0
    {
        Send_2401(0x00); // 无线发送数据   0x00是按键清零
        delay_ms(100);
        Send_2401(0x00); // 无线发送数据   0x00是按键清零   再次发送，防止收不到数据
    }

    // S
    if ((key_new[2] == 0) && (key_old[2] == 1)) // key3 按下   发S按下
    {
        Send_2401(KEY_S);           // 无线发送数据   0x16是按键值  代表S键按下了
        delay_ms(100);
    }
    if ((key_new[2] == 1) && (key_old[2] == 0)) // key3 抬起   发8个字节0
    {
        Send_2401(0x00); // 无线发送数据   0x00是按键清零
        delay_ms(100);
        Send_2401(0x00); // 无线发送数据   0x00是按键清零   再次发送，防止收不到数据
    }

    // D
    if ((key_new[3] == 0) && (key_old[3] == 1)) // key4 按下   发D按下
    {
        Send_2401(KEY_D); // 无线发送数据   0x07是按键值  代表D键按下了
        delay_ms(100);
    }
    if ((key_new[3] == 1) && (key_old[3] == 0)) // key4 抬起   发8个字节0
    {
        Send_2401(0x00); // 无线发送数据   0x00是按键清零
        delay_ms(100);
        Send_2401(0x00); // 无线发送数据   0x00是按键清零   再次发送，防止收不到数据
    }

    // Space
    if ((key_new[4] == 0) && (key_old[4] == 1)) // key5 按下   发Space按下
    {
        Send_2401(KEY_SPACE); // 无线发送数据   0x07是按键值  代表D键按下了
        delay_ms(100);
    }
    if ((key_new[4] == 1) && (key_old[4] == 0)) // key5 抬起   发8个字节0
    {
        Send_2401(0x00); // 无线发送数据   0x00是按键清零
        delay_ms(100);
        Send_2401(0x00); // 无线发送数据   0x00是按键清零   再次发送，防止收不到数据
    }

    // 控制录制
    if ((key_new[5] == 0) && (key_old[5] == 1)) // key5按下  认为按完一次按钮
    {
        if(!isRecording)
			{
				isRecording = 1;
				printf("Start\n");
			}
			else if(isRecording)
			{
				isRecording = 0;
				motion_index = 0;
				printf("End\n");
				
				nnom_feed_input();
        nnom_get_output();
        send_result(result);
				
				result = 100;
        memset(mpu6050_acc, 0, sizeof(mpu6050_acc));
				memset(calibration_mean,0,sizeof(calibration_mean));
			}
    }

    key_old[0] = key_new[0]; // 将新的按键值保存一下，用于下一次的比较
    key_old[1] = key_new[1]; //
    key_old[2] = key_new[2]; //
    key_old[3] = key_new[3]; //
    key_old[4] = key_new[4]; //
    key_old[5] = key_new[5]; //
}

int main(void)
{
    SystemInit(); // 系统时钟初始化
    GPIO_init(GPIO_A, GPIO_Pin_8, GPIO_Mode_Out_PP); // CE  24L01 端口初始化

    // 必须开usart，必须重定向printf，不然nnom_model_create()会卡死
    USART1_config(115200); // 串口1初始化  用于串口打印调试
    printf("uart1_ok\n");  // 打印一个字符串

    SPI2_Init_fun(); // 硬件SPI2  初始化  用于和24L01 通讯

    send_data_init(); // 2401发送的8个字节初始化

    TX_2401_init_send(); // 24L01  初始化为发送模式

    //========按键端口初始化=======================================
    GPIO_init(GPIO_B, GPIO_Pin_11, GPIO_Mode_IPU); // PB11
    GPIO_init(GPIO_B, GPIO_Pin_10, GPIO_Mode_IPU); // PB10
    GPIO_init(GPIO_B, GPIO_Pin_1, GPIO_Mode_IPU);  // PB1
    GPIO_init(GPIO_B, GPIO_Pin_0, GPIO_Mode_IPU);  // PB0
    GPIO_init(GPIO_A, GPIO_Pin_7, GPIO_Mode_IPU);  // PA7
    GPIO_init(GPIO_A, GPIO_Pin_6, GPIO_Mode_IPU);  // PA6 录制控制
    //------------------------------------------------------------
		
    //=========MPU6050================
    MPU6050_Init(); // MPU6050初始化
    //--------------------------------

#ifdef NNOM_USING_STATIC_MEMORY
    nnom_set_static_buf(nnom_buffer, sizeof(nnom_buffer));
#endif
    model = nnom_model_create();

    while (1)
    {
        MPU6050_GetData(&AX, &AY, &AZ, &GX, &GY, &GZ);
				read_key(); // 扫描按键，并执行无线发送数据和屏幕的操作
			
				if(isRecording)//如果在录制
				{
					printf("%d,%d,%d,%d,%d,%d\n", AX, AY, AZ, GX, GY, GZ);
          mpu6050_acc[motion_index][0] = AX;
          mpu6050_acc[motion_index][1] = AY;
          mpu6050_acc[motion_index][2] = AZ;
          motion_index++;
					
					if(motion_index >= maxlength)
					{
						motion_index = 0;
						isRecording = 0;
						printf("End\n");
						
						nnom_feed_input();
            nnom_get_output();
            send_result(result);
						
						result = 100;
            memset(mpu6050_acc, 0, sizeof(mpu6050_acc));
						memset(filtered_acc, 0, sizeof(filtered_acc));
						memset(calibration_mean,0,sizeof(calibration_mean));
					}
				}
   }
}

/// 重定向c库函数printf到串口，重定向后可使用printf函数  需要设置一下  在target 中 USE Micro Lib 打钩 才能用  在上面添加   #include "stdio.h"
int fputc(int ch, FILE *f) // 有个问题  函数没有声明  也可以用
{
    /* 发送一个字节数据到串口 */
    USART_SendData(USART1, (uint8_t)ch);

    /* 等待发送完毕 */
    while (!(USART1->SR & USART_FLAG_TXE))
        ;

    return (ch);
}

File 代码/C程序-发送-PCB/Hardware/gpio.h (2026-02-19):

#ifndef __GPIO_H
#define __GPIO_H
#include "stm32f10x.h"


#define GPIO_A	0x0000
#define GPIO_B	0x0001
#define GPIO_C	0x0002
#define GPIO_D	0x0003
#define GPIO_E	0x0004



#define  LED_H	  	GPIO_SetBits(GPIOC,GPIO_Pin_13)
#define  LED_L	  GPIO_ResetBits(GPIOC,GPIO_Pin_13)

#define	 LED_F			GPIOC->ODR^=GPIO_Pin_13


#define  PA1_ON	  		GPIO_SetBits(GPIOA,GPIO_Pin_1)
#define  PA2_ON	  		GPIO_SetBits(GPIOA,GPIO_Pin_2)
#define  PA3_ON	  		GPIO_SetBits(GPIOA,GPIO_Pin_3)
#define  PA4_ON	  		GPIO_SetBits(GPIOA,GPIO_Pin_4)
#define  PA5_ON	  		GPIO_SetBits(GPIOA,GPIO_Pin_5)
#define  PA6_ON	  		GPIO_SetBits(GPIOA,GPIO_Pin_6)
#define  PA7_ON	  		GPIO_SetBits(GPIOA,GPIO_Pin_7)
#define  PA8_ON	  		GPIO_SetBits(GPIOA,GPIO_Pin_8)
#define  PA9_ON	  		GPIO_SetBits(GPIOA,GPIO_Pin_9)
#define  PA10_ON	  	GPIO_SetBits(GPIOA,GPIO_Pin_10)
#define  PA11_ON	  	GPIO_SetBits(GPIOA,GPIO_Pin_11)
#define  PA12_ON	  	GPIO_SetBits(GPIOA,GPIO_Pin_12)
#define  PA13_ON	  	GPIO_SetBits(GPIOA,GPIO_Pin_13)
#define  PA14_ON	  	GPIO_SetBits(GPIOA,GPIO_Pin_14)
#define  PA15_ON	  	GPIO_SetBits(GPIOA,GPIO_Pin_15)

#define  PB0_ON	  		GPIO_SetBits(GPIOB,GPIO_Pin_0)
#define  PB1_ON	  		GPIO_SetBits(GPIOB,GPIO_Pin_1)
#define  PB2_ON	  		GPIO_SetBits(GPIOB,GPIO_Pin_2)
#define  PB3_ON	  		GPIO_SetBits(GPIOB,GPIO_Pin_3)
#define  PB4_ON	  		GPIO_SetBits(GPIOB,GPIO_Pin_4)
#define  PB5_ON	  		GPIO_SetBits(GPIOB,GPIO_Pin_5)
#define  PB6_ON	  		GPIO_SetBits(GPIOB,GPIO_Pin_6)
#define  PB7_ON	  		GPIO_SetBits(GPIOB,GPIO_Pin_7)
#define  PB8_ON	  		GPIO_SetBits(GPIOB,GPIO_Pin_8)
#define  PB9_ON	  		GPIO_SetBits(GPIOB,GPIO_Pin_9)
#define  PB10_ON	  	GPIO_SetBits(GPIOB,GPIO_Pin_10)
#define  PB11_ON	  	GPIO_SetBits(GPIOB,GPIO_Pin_11)
#define  PB12_ON	  	GPIO_SetBits(GPIOB,GPIO_Pin_12)
#define  PB13_ON	  	GPIO_SetBits(GPIOB,GPIO_Pin_13)
#define  PB14_ON	  	GPIO_SetBits(GPIOB,GPIO_Pin_14)
#define  PB15_ON	  	GPIO_SetBits(GPIOB,GPIO_Pin_15)

#define  PC14_ON	  	GPIO_SetBits(GPIOC,GPIO_Pin_14)
#define  PC15_ON	  	GPIO_SetBits(GPIOC,GPIO_Pin_15)



#define  PA1_OFF	  	GPIO_ResetBits(GPIOA,GPIO_Pin_1)
#define  PA2_OFF	  	GPIO_ResetBits(GPIOA,GPIO_Pin_2)
#define  PA3_OFF	  	GPIO_ResetBits(GPIOA,GPIO_Pin_3)
#define  PA4_OFF	  	GPIO_ResetBits(GPIOA,GPIO_Pin_4)
#define  PA5_OFF	  	GPIO_ResetBits(GPIOA,GPIO_Pin_5)
#define  PA6_OFF	  	GPIO_ResetBits(GPIOA,GPIO_Pin_6)
#define  PA7_OFF	  	GPIO_ResetBits(GPIOA,GPIO_Pin_7)
#define  PA8_OFF	  	GPIO_ResetBits(GPIOA,GPIO_Pin_8)
#define  PA9_OFF	  	GPIO_ResetBits(GPIOA,GPIO_Pin_9)
#define  PA10_OFF	  	GPIO_ResetBits(GPIOA,GPIO_Pin_10)
#define  PA11_OFF	  	GPIO_ResetBits(GPIOA,GPIO_Pin_11)
#define  PA12_OFF	  	GPIO_ResetBits(GPIOA,GPIO_Pin_12)
#define  PA13_OFF	  	GPIO_ResetBits(GPIOA,GPIO_Pin_13)
#define  PA14_OFF	  	GPIO_ResetBits(GPIOA,GPIO_Pin_14)
#define  PA15_OFF	  	GPIO_ResetBits(GPIOA,GPIO_Pin_15)


#define  PB0_OFF	  	GPIO_ResetBits(GPIOB,GPIO_Pin_0)
#define  PB1_OFF	  	GPIO_ResetBits(GPIOB,GPIO_Pin_1)
#define  PB2_OFF	  	GPIO_ResetBits(GPIOB,GPIO_Pin_2)
#define  PB3_OFF	  	GPIO_ResetBits(GPIOB,GPIO_Pin_3)
#define  PB4_OFF	  	GPIO_ResetBits(GPIOB,GPIO_Pin_4)
#define  PB5_OFF	  	GPIO_ResetBits(GPIOB,GPIO_Pin_5)
#define  PB6_OFF	  	GPIO_ResetBits(GPIOB,GPIO_Pin_6)
#define  PB7_OFF	  	GPIO_ResetBits(GPIOB,GPIO_Pin_7)
#define  PB8_OFF	  	GPIO_ResetBits(GPIOB,GPIO_Pin_8)
#define  PB9_OFF	  	GPIO_ResetBits(GPIOB,GPIO_Pin_9)
#define  PB10_OFF	  	GPIO_ResetBits(GPIOB,GPIO_Pin_10)
#define  PB11_OFF	  	GPIO_ResetBits(GPIOB,GPIO_Pin_11)
#define  PB12_OFF	  	GPIO_ResetBits(GPIOB,GPIO_Pin_12)
#define  PB13_OFF	  	GPIO_ResetBits(GPIOB,GPIO_Pin_13)
#define  PB14_OFF	  	GPIO_ResetBits(GPIOB,GPIO_Pin_14)
#define  PB15_OFF	  	GPIO_ResetBits(GPIOB,GPIO_Pin_15)

#define  PC14_OFF	  	GPIO_ResetBits(GPIOC,GPIO_Pin_14)
#define  PC15_OFF	  	GPIO_ResetBits(GPIOC,GPIO_Pin_15)




#define  READ_A0			GPIO_ReadInputDataBit(GPIOA,GPIO_Pin_0)//A0
#define  READ_A1			GPIO_ReadInputDataBit(GPIOA,GPIO_Pin_1)//A1
#define  READ_A2			GPIO_ReadInputDataBit(GPIOA,GPIO_Pin_2)//A2
#define  READ_A3			GPIO_ReadInputDataBit(GPIOA,GPIO_Pin_3)//A3
#define  READ_A4			GPIO_ReadInputDataBit(GPIOA,GPIO_Pin_4)//A4
#define  READ_A5			GPIO_ReadInputDataBit(GPIOA,GPIO_Pin_5)//A5
#define  READ_A6			GPIO_ReadInputDataBit(GPIOA,GPIO_Pin_6)//A6
#define  READ_A7			GPIO_ReadInputDataBit(GPIOA,GPIO_Pin_7)//A7
#define  READ_A8			GPIO_ReadInputDataBit(GPIOA,GPIO_Pin_7)//A8
#define  READ_A9			GPIO_ReadInputDataBit(GPIOA,GPIO_Pin_7)//A9
#define  READ_A10			GPIO_ReadInputDataBit(GPIOA,GPIO_Pin_7)//A10
#define  READ_A11			GPIO_ReadInputDataBit(GPIOA,GPIO_Pin_7)//A11
#define  READ_A12			GPIO_ReadInputDataBit(GPIOA,GPIO_Pin_7)//A12
#define  READ_A13			GPIO_ReadInputDataBit(GPIOA,GPIO_Pin_7)//A13
#define  READ_A14			GPIO_ReadInputDataBit(GPIOA,GPIO_Pin_7)//A14
#define  READ_A15			GPIO_ReadInputDataBit(GPIOA,GPIO_Pin_7)//A15
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

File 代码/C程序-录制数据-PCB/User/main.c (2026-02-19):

#include "stm32f10x.h"                  // Device header
#include "Delay.h"
#include "OLED.h"
#include "MPU6050.h"
#include "usart.h"
#include "stdio.h"


int16_t AX, AY, AZ, GX, GY, GZ;
uint8_t Key_Old = 1;
uint8_t Key_New = 1;
uint8_t motion_index = 0;
uint8_t isRecording = 0;

//重定向c库函数printf到串口，重定向后可使用printf函数  需要设置一下  在target 中 USE Micro Lib 打钩 才能用  在上面添加   #include "stdio.h"
int fputc(int ch, FILE *f)//有个问题  函数没有声明  也可以用 
{
	/* 发送一个字节数据到串口 */
	USART_SendData(USART1, (uint8_t) ch);
		
	/* 等待发送完毕 */
	while (!(USART1->SR & USART_FLAG_TXE));
	return ch;
}

void Key_Init(void)//初始化按钮A6
{
	RCC_APB2PeriphClockCmd(RCC_APB2Periph_GPIOA,ENABLE);
	
	GPIO_InitTypeDef GPIO_InitStruct;
	GPIO_InitStruct.GPIO_Mode = GPIO_Mode_IPU;
	GPIO_InitStruct.GPIO_Pin = GPIO_Pin_6;
	GPIO_InitStruct.GPIO_Speed = GPIO_Speed_50MHz;
	GPIO_Init(GPIOA,&GPIO_InitStruct);
}


int main(void)
{
	MPU6050_Init();
	Key_Init();
	USART1_config(115200);//串口1初始化  用于串口打印调试
	printf("uart1_ok\n");//打印一个字符串
	
	while(1)
	{
		MPU6050_GetData(&AX, &AY, &AZ, &GX, &GY, &GZ);
		Key_Old = Key_New;
		Key_New = GPIO_ReadInputDataBit(GPIOA,GPIO_Pin_6);
		if(Key_Old == 1 && Key_New == 0)//如果按钮被按下
		{
			if(!isRecording)
			{
				isRecording = 1;
				printf("Start\n");
			}
		}
		if(isRecording)//如果在录制
		{
			printf("%d,%d,%d,%d,%d,%d\n",AX,AY,AZ,GX,GY,GZ);
			motion_index ++;
			if(motion_index >= 100)
			{
				motion_index = 0;
				isRecording = 0;
				printf("End\n");
			}
		}
	}
}

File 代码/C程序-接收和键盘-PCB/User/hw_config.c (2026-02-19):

#include "stm32f10x.h"
#include "hw_config.h"
#include "usb_lib.h"
#include "usb_desc.h"
#include "usb_pwr.h"

//定义使用外部晶振  ,如果不定义就使用内部的HSI高速RC震荡
#define USB_HSE_AS_SYS_CLOCK

#define USB_DISCONNECT                      GPIOG
#define USB_DISCONNECT_PIN                  GPIO_Pin_11

//本开发板只用了 PA.0，PC.13模拟鼠标动作
#define GPIO_Pin_up                         GPIO_Pin_8  /* PA.8 */
#define GPIO_Pin_down                       GPIO_Pin_3 /* PD.3 */
#define GPIO_Pin_right                      GPIO_Pin_0  /* PA.0 */
#define GPIO_Pin_left                       GPIO_Pin_13  /* PC.13 */

#define RCC_APB2Periph_GPIO_DISCONNECT      RCC_APB2Periph_GPIOG
//#define GPIO_RIGHT                          GPIOC
//#define GPIO_LEFT                           GPIOC
// #define GPIO_DOWN                           GPIOB
// #define GPIO_UP                             GPIOB
#define GPIO_Click_left                     GPIOC
#define GPIO_Click_right                    GPIOA
#define GPIO_Click_up                    		GPIOA
#define GPIO_Click_down	                   	GPIOD

//#define GPIO_KEY                            GPIOB
#define RCC_APB2Periph_ALLGPIO                 (RCC_APB2Periph_GPIOA \
                                              | RCC_APB2Periph_GPIOB \
                                              | RCC_APB2Periph_GPIOC \
                                              | RCC_APB2Periph_GPIOD \
                                              | RCC_APB2Periph_GPIOE )
/* 变量声明------------------------------------------------------------------*/
ErrorStatus HSEStartUpStatus;
EXTI_InitTypeDef EXTI_InitStructure;

/*******************************************************************************
  * @函数名称	RCC_HSI_Configuration
  * @函数说明   配置使用内部的HSI作为系统时钟源
  * @输入参数   无
  * @输出参数   无
  * @返回参数   无
*******************************************************************************/
void RCC_HSI_Configuration(void)
{
    RCC_DeInit();
    //使能HSI
    RCC_HSICmd(ENABLE);
    while (RCC_GetFlagStatus(RCC_FLAG_HSIRDY) == RESET)
    {
    }        //等待HSI准备好
    //使能Falsh 的预取
    FLASH_PrefetchBufferCmd(FLASH_PrefetchBuffer_Enable);
    //设置Falsh等待一个周期
    FLASH_SetLatency(FLASH_Latency_1);
    // 设置HCLK = SYSCLK 
    RCC_HCLKConfig(RCC_SYSCLK_Div1);
    //设置 PCLK2 = HCLK 
    RCC_PCLK2Config(RCC_HCLK_Div1);
    // PCLK1 = HCLK/2 
    RCC_PCLK1Config(RCC_HCLK_Div2);
    //设置 PLLCLK = 8MHz * 6 = 48 MHz 
    RCC_PLLConfig(RCC_PLLSource_HSI_Div2, RCC_PLLMul_12);
    //使能 PLL 
    RCC_PLLCmd(ENABLE);
    //等待PLL稳定
    while (RCC_GetFlagStatus(RCC_FLAG_PLLRDY) == RESET)
    {
    }
    //选取PLL作为系统时钟
    RCC_SYSCLKConfig(RCC_SYSCLKSource_PLLCLK);
    //等待PLL选为系统时钟
    while (RCC_GetSYSCLKSource() != 0x08)
    {
    }
}

/*******************************************************************************
  * @函数名称	Set_System
  * @函数说明   配置系统时钟
  * @输入参数   无
  * @输出参数	无
  * @返回参数   无
*******************************************************************************/



void Set_System(void)
{
    //GPIO_InitTypeDef GPIO_InitStructure;

    //配置系统时钟，初始化Falsh接口，初始化PLL
    
	
	
	
	
	/*
#ifdef USB_HSE_AS_SYS_CLOCK    //如果使用外部晶振就用这个函数
    SystemInit();
#else
    //如果使用内部RC晶振作为时钟源就需要配置
    RCC_HSI_Configuration();
#endif
	*/
	
	RCC_HSI_Configuration();
	
	
	/*
    //设置所有引脚为输入
    GPIO_AINConfig();

    RCC_APB2PeriphClockCmd(RCC_APB2Periph_GPIO_DISCONNECT, ENABLE);


    //配置 USB_DISCONNECT引脚为上拉
    GPIO_InitStructure.GPIO_Pin = USB_DISCONNECT_PIN;
    GPIO_InitStructure.GPIO_Speed = GPIO_Speed_2MHz;
    GPIO_InitStructure.GPIO_Mode = GPIO_Mode_Out_PP;
    GPIO_Init(USB_DISCONNECT, &GPIO_InitStructure);

	
    //使能鼠标按键的时钟
    RCC_APB2PeriphClockCmd(RCC_APB2Periph_GPIOA|RCC_APB2Periph_GPIOC|RCC_APB2Periph_GPIOD, ENABLE);

    //配置按键的IO
		GPIO_InitStructure.GPIO_Pin = GPIO_Pin_right;
    GPIO_InitStructure.GPIO_Mode = GPIO_Mode_IPU;
    GPIO_Init(GPIO_Click_right, &GPIO_InitStructure);

    GPIO_InitStructure.GPIO_Pin = GPIO_Pin_left;
    GPIO_Init(GPIO_Click_left, &GPIO_InitStructure);
		
		GPIO_InitStructure.GPIO_Pin = GPIO_Pin_up;
    GPIO_Init(GPIO_Click_up, &GPIO_InitStructure);

    GPIO_InitStructure.GPIO_Pin = GPIO_Pin_down;
    GPIO_Init(GPIO_Click_down, &GPIO_InitStructure);
		*/
}

/*******************************************************************************
  * @函数名称	Set_USBClock
  * @函数说明   配置USB系统时钟
  * @输入参数   无
  * @输出参数	无
  * @返回参数   无
*******************************************************************************/
void Set_USBClock(void)
{
	
    //配置USB时钟
#ifdef USB_HSE_AS_SYS_CLOCK    //如果使用外部晶振就用这个函数
    RCC_USBCLKConfig(RCC_USBCLKSource_PLLCLK_1Div5);
#else
    RCC_USBCLKConfig(RCC_USBCLKSource_PLLCLK_Div1);
#endif
    // 使能USB时钟 
    RCC_APB1PeriphClockCmd(RCC_APB1Periph_USB, ENABLE);
	
	
	
	
	//RCC_USBCLKConfig(RCC_USBCLKSource_PLLCLK_Div1);
	//RCC_APB1PeriphClockCmd(RCC_APB1Periph_USB, ENABLE);
}
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

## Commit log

2026-02-19 初次提交：上传现有项目
    [3DShell-外壳主体_B.stl, 3DShell-外壳主体_T.stl, 3DShell_外壳零件_T.stl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]
2026-02-19 更新README，增加项目相关信息
    Added hardware and software components details to README.
